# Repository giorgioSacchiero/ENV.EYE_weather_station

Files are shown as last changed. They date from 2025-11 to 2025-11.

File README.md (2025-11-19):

# Env.Eye - 20 Years Arduino Contest Project

## Introduzione
ENV.EYE è il progetto di una stazione meteo autonoma sperimentale. L’idea è nata dall’esigenza di dar vita a qualcosa di originale sfruttando le potenzialità e le versatilità delle soluzioni Arduino. 
Nel nostro caso abbiamo voluto rivisitare il modello classico della stazione meteo IoT, con alcune peculiarità: un contatore Geiger capace di funzionare con un’alimentazione in bassissima tensione (attorno ai 2.2 Volt) e la possibilità di rendere il tutto indipendente attraverso un pannello fotovoltaico e due supercondensatori come riserva di energia. Ciò ci ha ovviamente vincolati a prestare la massima attenzione ai consumi, in ogni operazione e/o misura eseguita.
Complessivamente il progetto si occupa della raccolta delle variabili caratteristiche dell’ambiente (temperatura, umidità, pressione atmosferica, ecc.) e del loro caricamento on-line come un’occhio sull’ambiente, da cui il nome “Env.Eye”. 
Per raggiungere lo scopo sono stati realizzati due dispositivi: un modulo chiamato Spot che raccoglie e invia i dati ambientali al secondo modulo chiamato Hub, che ha il compito di rendere disponibili i dati acquisiti in una bacheca on-line realizzata con Arduino Cloud.

## Elettronica (./hardware/Electronics/)
Il progetto si compone di due PCB ciascuna relativa ad uno dei due moduli.
1. La PCB del modulo SPOT incorpora tutta la sensoristica, la sezione di ricarica e alimentazione, il modulo di comunicazione e la scheda Arduino Nano ESP32.
2. La PCB del modulo HUB, più semplice, si compone di un modulo LoRa per la comunicazione radio, un ulteriore scheda Arduino Nano ESP32 ed una terna di LED RGB a indicarne lo stato.

Per l'assemblaggio delle schede è fortemente consigliato ordinare uno stencil poiché semplifica e velocizza il lavoro. Quest'ultimo è acquistabile assieme alle PCB una volta caricato il file di produzione nell'interfaccia del produttore scelto. Nel nostro caso, ci siamo affidati a [JLC-PCB](https://jlcpcb.com/).

I file di progetto sono realizzati su EasyEDA e sono disponibili nella cartella indicata nel titoletto.

**NOTA:** La rev1 presenta dei malfunzionamenti. A breve verrà resa disponibile la versione corretta.

## Meccanica e File CAD (./hardware/CAD/)

## Programmazione (./software/)
Il firmware di Spot e Hub sono disponibili nella cartella sopra indicata. Per la programmazione del primo è stato usato Visual Studio Code con l'estensione ESP-IDF di Espressif. Invece, per quanto riguarda il secondo, è programmato nell'interfaccia Arduino Cloud, oppure attraverso Arduino IDE 2.0.

## Licenza
L'intero progetto è disponibile per il riutilizzo e la modifica sotto licenza CC BY-NC 4.0. Qualsiasi utilizzo commerciale è vietato salvo esplicita autorizzazione dei sottoscritti autori:
1. Giacomo Pascon - (www.progettipascon.altervista.org) - giacomo.pascon@gmail.com 
2. Cristian Piccone - cristian.piccone@gmail.com
3. Giorgio Sacchiero - sacchiero2005@gmail.com

Ulteriori informazioni sono presenti nel file LICENSE.txt e a [questo link](https://creativecommons.org/licenses/by-nc/4.0/).

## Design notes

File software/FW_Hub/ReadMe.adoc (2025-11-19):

:Author: ar-giacomo
:Email:
:Date: 26/09/2025
:Revision: version#
:License: Public Domain

= Project: {Project}

Describe your project

== Step 1: Installation
Please describe the steps to install this project.

For example:

1. Open this file
2. Edit as you like
3. Release to the World!

== Step 2: Assemble the circuit

Assemble the circuit following the diagram layout.png attached to the sketch

== Step 3: Load the code

Upload the code contained in this sketch on to your board

=== Folder structure

....
 sketch123                => Arduino sketch folder
  ├── sketch123.ino       => main Arduino file
  ├── schematics.png      => (optional) an image of the required schematics
  ├── layout.png          => (optional) an image of the layout
  └── ReadMe.adoc         => this file
....

=== License
This project is released under a {License} License.

=== Contributing
To contribute to this project please contact: 

=== BOM
Add the bill of the materials you need for this project.

|===
| ID | Part name      | Part number | Quantity
| R1 | 10k Resistor   | 1234-abcd   | 10       
| L1 | Red LED        | 2345-asdf   | 5        
| A1 | Arduino Zero   | ABX00066    | 1        
|===

=== Help
This document is written in the _AsciiDoc_ format, a markup language to describe documents. 
If you need help you can search the http://www.methods.co.nz/asciidoc[AsciiDoc homepage]
or consult the http://powerman.name/doc/asciidoc[AsciiDoc cheatsheet]

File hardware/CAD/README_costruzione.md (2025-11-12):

parte meccanica / costruttiva:
- materiali:
    - filo o-ring / diam: 1.6 mm / lenght: 1 m;
    - 4 inserti M3 in ottone da inrerire a caldo;
    - 4 viti M3 con testa svasata;
    - 3 piedini M3 per PCB spessi 5mm;
    - maschi M3, M4 per filettare;
    - tavola di legno spessa 10/15 mm;
    - profili a "L" in acciaio.

- componenti:
    I componenti della scatola si trovano nella cartella "componenti" divisi tra le cartelle "Spot" e "Hub". I componenti da utilizzare nella costruzione sono le ultime versioni dei componenti, identificate dal pedice "_v3" per la verione 3 di un file. 

- stampe 3D:
    Consiglio per lo Spot è quello di stampare in materiali resistenti come PETG o ABS (io ho utilizzato PETG), mentre per l'Hub consiglio un materiale traslucido anche se poco resistente. questo perché il modulo presenta 3 led di diagnostica che devono essere visibili         dall'esterno.

- montaggio:
  - Spot:
    - Inserire a caldo gli inserti in ottone nei 4 fori sotto il componente "scatola_corpo_v3" e fissare il "tappino_TPU" sulla posta della USB con una vitina molto piccola, attorno a una M2 (va bene una vite autofilettante come no, a scelta);
    - tagliare a misura l'o-ring, inserirlo nella corsia tra "scatola_corpo_v3" e "scatola_coperchio_principale" e incollarne le estremità l'una con l'altra con dell'attach;
    - filettare i 3 fori delle torrette del coperchio_principale con maschio M3 e avvitarci i 3 piedini in ottone;
    - tagliare la tavola di legno con le misure del componente "legno" (trascurare lo spessore) e realizzare indicativamente il resto della struttura con cui ancorare lo spot a un qualsiasi supporto verticale;
    - praticare un foro sulla superficie inclinata della scatola per permettere il passaggio dei fili del pannello e incollarci sopra il pannello solare con del silicone per impermeabilizzare;
    - montare la scatola sulla tavola con viti autofilettanti per legno, mantenendo una spaziatura al di sotto della scatola di almeno 5 mm (lo spessore di un dado M4 / M5);
    - praticare sulla parte restante della tavola 8 fori filettati M4 per montare anemometro e pala per la direzione del vento e montarli.
      
        [fare attenzione a filettare i fori dal punto in cui la vite verrà avvitata, perchè potrebbe non essere abbastanza lungo il maschio per filettare fin dall'altra parte della tavola. Inoltre curarci di praticare bene i fori per non risciare disallineamenti]; 
    - connettere i sensori esterni alla scheda e chiudere il tutto.
     
  - Hub:

      molto più semplice dello Spot, basta inserire la schedina dell'Hub nella cava disegnata allo scopo, volendo fissare la scheda con viti M3 nei due fori della scheda e incastrare parte sotto con parte sopra. Fine.

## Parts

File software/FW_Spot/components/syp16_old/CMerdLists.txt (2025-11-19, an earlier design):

idf_component_register(SRCS "syp16.cpp" INCLUDE_DIRS "." REQUIRES driver)

target_compile_options(${COMPONENT_LIB} PRIVATE -std=gnu++23)

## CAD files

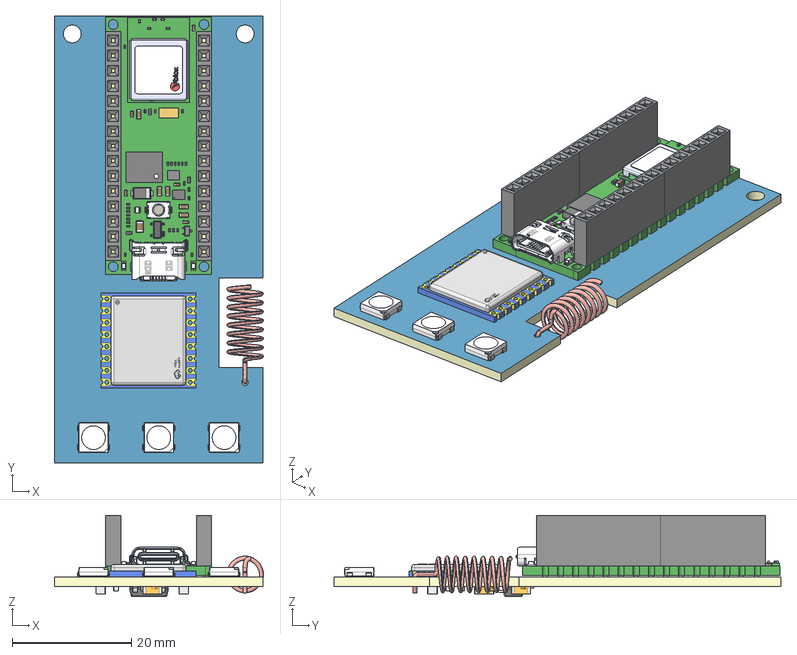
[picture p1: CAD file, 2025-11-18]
hardware/CAD/PCB_Models/PCB_hub_rev_0/PCB_hub_rev_0.step
35.1 x 75.0 x 13.6 mm
Board~ZvB2
TopCopper~ZvB2
BottomCopper~ZvB2
TopFpcStiffener~ZvB2
BottomFpcStiffener~ZvB2
Arduino_NANO_ESP32~libraries\Arduino_NANO_ESP32.step~ZvB2 x 184
C1206~C1206_L3.2-W1.6-H1.3~ZvB2 x 3
C0603~C0603_L1.6-W0.8-H0.8~ZvB2 x 3
LED-SMD_4P-L5.0-W5.0-BL_XL-5050RGBC~LED-SMD_4P-L5.0-W5.0-BL_ XL-5050RGBC~ZvB2 x 3
SOT-223-3_L6.5-W3.4-P2.30-LS7.0-BR-1~SOT-223-3_ L6.5-W3.4-P2.30-LS7.0-BR-1~ZvB2
COMM-SMD_LORA1276-C1-915MHZ~COMM-SMD_LORA1276-C1-915MHZ~ZvB2
ANT-TH_VG868SNX18-5W2~ANT-TH_VG868SNX18-5W2~ZvB2

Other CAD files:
hardware/CAD/OldVersions/Assembly1.0022.iam
hardware/CAD/OldVersions/adattatore per motore.0001.ipt
hardware/CAD/OldVersions/asta.0006.ipt
hardware/CAD/OldVersions/cupola alta di protezione.0007.ipt
hardware/CAD/OldVersions/guarnizione motore.0004.ipt
hardware/CAD/OldVersions/lampione.0001.ipt
hardware/CAD/OldVersions/legno 1.0001.ipt
hardware/CAD/OldVersions/legno 2.0004.ipt
hardware/CAD/OldVersions/legno.0007.ipt
hardware/CAD/OldVersions/pannello solare.0003.ipt
hardware/CAD/OldVersions/piedino.0001.ipt
hardware/CAD/OldVersions/sacatola coperchio principale.0019.ipt
hardware/CAD/OldVersions/scatola - corpo sotto.0004.ipt
hardware/CAD/OldVersions/scatola corpo.0024.ipt
hardware/CAD/OldVersions/spazzola - asta.0002.ipt
hardware/CAD/OldVersions/spazzola - spazzola.0002.ipt
hardware/CAD/OldVersions/supporto asta.0003.ipt
hardware/CAD/OldVersions/tappino tpu.0001.ipt
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

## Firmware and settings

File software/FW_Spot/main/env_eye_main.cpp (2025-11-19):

/* ------------------------- C++ (.cpp) FILE INFORMATION ------------------------- */
/**
 * PROJECT:         ENV.EYE SPOT Project
 * 
 * FILE:            "env_eye_main.cpp"
 * 
 */

#include <stdio.h>
#include <stdlib.h>
#include <inttypes.h>
#include <math.h>
#include "freertos/FreeRTOS.h"
#include "freertos/task.h"

#include "esp_log.h"
#include "driver/gpio.h"
#include "driver/rtc_io.h"
#include "driver/ledc.h"
#include "esp_adc/adc_oneshot.h"
#include "esp_sleep.h"
#include "esp_timer.h"

#include "nano_esp32.hpp"
#include "hdc1080.hpp"
#include "wf183de.hpp"
#include "syp16.hpp"
#include "lora.h"

#include "env_eye_pinout.h"
#include "env_eye_config.h"
#include "env_eye_lora.hpp"

/* ------------------------- MACRO DEFINITION -------------------------*/
#define TAG "SPOT"

#define ERR_LOG_RET_ERR(FUNCT)  \
if ( esp_err_t _ERR = FUNCT != ESP_OK ) \
{   \
    ESP_LOGE(TAG, "ERROR (%X) at line %d. Description: %s", _ERR, __LINE__, esp_err_to_name(_ERR)); \
    return _ERR; \
}

/* ------------------------- NAMESPACES ------------------------- */
using namespace Nano_ESP32;

/* ------------------------- GLOBAL VARIABLES ------------------------- */
adc_oneshot_unit_handle_t adc_unit_handle;
RTC_DATA_ATTR int wakeup_count = 0;
enum direction_t {N, NE, E, SE, S, SW, W, NW, UNK};
uint16_t geiger_pulses = 0;

/* ------------------------- LOCAL FUNCTIONS ------------------------- */
esp_err_t gpio_configure();

inline void sensor_5v_turn_on();
inline void sensor_5v_turn_off();

inline void sensor_3v3_turn_on();
inline void sensor_3v3_turn_off();

inline void sensor_25v_turn_on();
inline void sensor_25v_turn_off();

inline void geiger_25v_turn_on();
inline void geiger_25v_turn_off();

inline void geiger_5v_turn_on();
inline void geiger_5v_turn_off();

inline void geiger_turn_on();
inline void geiger_turn_off();

float get_wind_speed();
direction_t get_wind_dir();

float get_noise_level();

float get_pollution_level(SYP16 _syp);

void geiger_isr(void *_args);
float get_radiation_level();

void lora_send_packet(lora_payload_t *_payload);

void esp_enter_sleep();

extern "C" void app_main(void)
{
    //Wait some time for serial monitor connection
    vTaskDelay(100);

    //Configure GPIO
    ESP_ERROR_CHECK(configure_nano());
    ESP_ERROR_CHECK(gpio_configure());

    //Turn on 3.3V sensor rail and initialize communicatin
    sensor_3v3_turn_on();
    vTaskDelay(100);
    
    HDC1080 hdc(rev1_pinout.I2C_SDA, rev1_pinout.I2C_SCL, 100000, I2C_NUM_0, 1000, true);
    hdc.configureDefault();
    WF183DE wf(rev1_pinout.I2C_SDA, rev1_pinout.I2C_SCL, 100000, I2C_NUM_0, 1000, false);
    
    //Configure LoRa module
    lora_configure(100000, 868000000, 7, 7, 1, true);

    vTaskDelay(100);
    ESP_LOGE(TAG, "Wakeup num %d", wakeup_count);

    while(1)
    {
        lora_payload_t payload;
        lora_init_payload(&payload);

        switch(wakeup_count)
        {
            //----> FIRST START, wait some time before measuring.
            case 0:
                wakeup_count++;
                esp_enter_sleep();
                break;
            
            //----> MEASURE ONLY TEMP., HUM. AND PRESSURE
            case 1:     
                hdc.measure();

                //Perform two measures to avoid null reading
                wf.measurePressure();
                vTaskDelay(10);
                wf.measurePressure();

                payload.temperature = hdc.getTemp();
                payload.humidity = hdc.getHum();
                payload.air_pressure = wf.getPressure();
                
                lora_send_packet(&payload);
                //wait for Lora module to send the data before shutting off
                vTaskDelay(100);
                sensor_3v3_turn_off();
                
                wakeup_count++;
                esp_enter_sleep();
            break;
            
            //----> MEASURE TEMP., HUM., PRESSURE AND WIND
            case 2:
                hdc.measure();
                
                //Perform two measures to avoid null reading
                wf.measurePressure();
                vTaskDelay(10);
                wf.measurePressure();

                payload.temperature = hdc.getTemp();
                payload.humidity = hdc.getHum();
                payload.air_pressure = wf.getPressure();
                
                if(gpio_get_level(rev1_pinout.CAP_VOLTAGE_OK))
                {
                    sensor_25v_turn_on();
                    vTaskDelay(150);
                    payload.wind_spd = get_wind_speed();
                    payload.wind_dir = (int16_t)get_wind_dir();
                    sensor_25v_turn_off();
                
                    sensor_5v_turn_on();
                    vTaskDelay(300);
                    payload.noise_level = get_noise_level();
                    sensor_5v_turn_off();

                    wakeup_count++;
                }
                else wakeup_count = 1;
                
                lora_send_packet(&payload);
                vTaskDelay(100);
                //wait for Lora module to send the data before shutting off
                sensor_3v3_turn_off();                

                esp_enter_sleep();
            break;

            //----> MEASURE TEMP., HUM., PRESSURE, BACKGR. NOISE AND RADIATION 
            case 3: //temp + hum + press + mic + geig
                hdc.measure();
                
                //Perform two measures to avoid null reading
                wf.measurePressure();
                vTaskDelay(10);
                wf.measurePressure();

                payload.temperature = hdc.getTemp();
                payload.humidity = hdc.getHum();
                payload.air_pressure = wf.getPressure();
 
                if(gpio_get_level(rev1_pinout.CAP_VOLTAGE_OK))
                {               
                    sensor_5v_turn_on();
                    vTaskDelay(300);
                    payload.noise_level = get_noise_level();
                    sensor_5v_turn_off();

                    geiger_turn_on();
                    vTaskDelay(50);
                    float usievert_h = get_radiation_level();
                    if(usievert_h != -1) 
                    {
                        payload.radiation_level = usievert_h;
                        wakeup_count++;
                    }
                    geiger_turn_off();
                }
                
                lora_send_packet(&payload);
                vTaskDelay(100);
                //wait for Lora module to send the data before shutting off
                sensor_3v3_turn_off();                
                esp_enter_sleep();
            break;

            //----> MEASURE TEMP., HUM., PRESSURE, BACKGR. NOISE AND POLLUTION 
            case 4: //temp + hum + press + wind + mic + air
                hdc.measure();
                
                //Perform two measures to avoid null reading
                wf.measurePressure();
                vTaskDelay(10);
                wf.measurePressure();

                payload.temperature = hdc.getTemp();
                payload.humidity = hdc.getHum();
                payload.air_pressure = wf.getPressure();

                if(gpio_get_level(rev1_pinout.CAP_VOLTAGE_OK))
                {
                    sensor_5v_turn_on();
                    vTaskDelay(150);
                    SYP16 syp(rev1_pinout.UART_TX, rev1_pinout.UART_RX, UART_NUM_1, SYP16_QUESTION_ANSWER_MODE);
                    vTaskDelay(150);
                    payload.noise_level = get_noise_level();
                
                    payload.air_pollution_level = get_pollution_level(syp);
                    wakeup_count = 2; //Start again from measuring wind 
                }
                //When supercapacitors have low charge, measure with geiger first, since it draws less power.
                else wakeup_count = 3;
                sensor_5v_turn_off();

                lora_send_packet(&payload);
                vTaskDelay(100);
                sensor_3v3_turn_off();
                
                esp_enter_sleep();
            break;
        }

        vTaskDelay(100); //Never reached in normal operation
    }
}

/* ------------------------- GPIO Management ------------------------- */
esp_err_t gpio_configure()
{
    //Initialize digital inputs
    gpio_config_t _pin_config;
    _pin_config.mode = GPIO_MODE_INPUT;
    _pin_config.intr_type = GPIO_INTR_DISABLE;
    _pin_config.pin_bit_mask = 1ULL << rev1_pinout.CAP_VOLTAGE_OK | 1ULL<<rev1_pinout.GEIGER_IN;
    _pin_config.pull_down_en = GPIO_PULLDOWN_DISABLE;
    _pin_config.pull_up_en = GPIO_PULLUP_ENABLE;
    ERR_LOG_RET_ERR(gpio_config(&_pin_config));

    //Geiger input interrupt
    gpio_set_intr_type(rev1_pinout.GEIGER_IN, GPIO_INTR_NEGEDGE);
    gpio_install_isr_service(ESP_INTR_FLAG_IRAM);
    gpio_isr_handler_add(rev1_pinout.GEIGER_IN, geiger_isr, NULL);
    gpio_intr_disable(rev1_pinout.GEIGER_IN);

    //Initialize digital outputs
    _pin_config.mode = GPIO_MODE_OUTPUT;
    _pin_config.pin_bit_mask = 1ULL<<rev1_pinout.EN_3V3_RAIL;
    ERR_LOG_RET_ERR(gpio_config(&_pin_config));
    ERR_LOG_RET_ERR(gpio_set_level(rev1_pinout.EN_3V3_RAIL, 1));

    _pin_config.pin_bit_mask = 1ULL<<rev1_pinout.EN_5V_SENSOR_RAIL | 1ULL<<rev1_pinout.EN_5V_GEIGER_RAIL | 1ULL<<rev1_pinout.EN_25V_RAIL | 1ULL<<rev1_pinout.EN_SERVO_RAIL;
    _pin_config.pull_down_en = GPIO_PULLDOWN_DISABLE;
    _pin_config.pull_up_en = GPIO_PULLUP_DISABLE;
    ERR_LOG_RET_ERR(gpio_config(&_pin_config));
    ERR_LOG_RET_ERR(gpio_set_level(rev1_pinout.EN_5V_SENSOR_RAIL, 0));
    ERR_LOG_RET_ERR(gpio_set_level(rev1_pinout.EN_5V_GEIGER_RAIL, 0));
    ERR_LOG_RET_ERR(gpio_set_level(rev1_pinout.EN_25V_RAIL, 0));
    ERR_LOG_RET_ERR(gpio_set_level(rev1_pinout.EN_SERVO_RAIL, 0));
    
    //Initialize analog inputs
    adc_oneshot_unit_init_cfg_t _unit_config;
    _unit_config.unit_id = ADC_UNIT_1;
    _unit_config.ulp_mode = ADC_ULP_MODE_DISABLE;
    ERR_LOG_RET_ERR(adc_oneshot_new_unit(&_unit_config, &adc_unit_handle));

    adc_oneshot_chan_cfg_t _channel_config;
    _channel_config.bitwidth = ADC_BITWIDTH_DEFAULT;
    _channel_config.atten = ADC_ATTEN_DB_12;
    ERR_LOG_RET_ERR(adc_oneshot_config_channel(adc_unit_handle, rev1_pinout.MIC_IN, &_channel_config));
    ERR_LOG_RET_ERR(adc_oneshot_config_channel(adc_unit_handle, rev1_pinout.WIND_SPEED_IN, &_channel_config));
    ERR_LOG_RET_ERR(adc_oneshot_config_channel(adc_unit_handle, rev1_pinout.WIND_DIR_IN, &_channel_config));

    return ESP_OK;
}

// -------- Toggle 3V3 rail -------- 
inline void sensor_3v3_turn_on()
{
    gpio_set_level(rev1_pinout.EN_3V3_RAIL, 0);
}

inline void sensor_3v3_turn_off()
{
    gpio_set_level(rev1_pinout.EN_3V3_RAIL, 1);
}

// -------- Toggle 5V sensor rail -------- 
inline void sensor_5v_turn_on()
{
    gpio_set_level(rev1_pinout.EN_5V_SENSOR_RAIL, 1);
}

inline void sensor_5v_turn_off()
{
    gpio_set_level(rev1_pinout.EN_5V_SENSOR_RAIL, 0);
}

// -------- Toggle 5V geiger rail --------
inline void geiger_5v_turn_on()
{
    gpio_set_level(rev1_pinout.EN_5V_GEIGER_RAIL, 1);
}

inline void geiger_5v_turn_off()
{
    gpio_set_level(rev1_pinout.EN_5V_GEIGER_RAIL, 0);
}

// -------- Toggle 25V rail -------- 
inline void sensor_25v_turn_on()
{
    gpio_set_level(rev1_pinout.EN_SERVO_RAIL, 1);
}

inline void sensor_25v_turn_off()
{
    gpio_set_level(rev1_pinout.EN_SERVO_RAIL, 0);
}

// -------- Toggle 25V rail for geiger supply -------- 
inline void geiger_25v_turn_on()
{
    gpio_set_level(rev1_pinout.EN_25V_RAIL, 1);
}

inline void geiger_25v_turn_off()
{
    gpio_set_level(rev1_pinout.EN_25V_RAIL, 0);
}

// -------- Toggle geiger supply --------
inline void geiger_turn_on()
{
    geiger_25v_turn_on();
    geiger_5v_turn_on();
}

inline void geiger_turn_off()
{
    geiger_25v_turn_on();
    geiger_5v_turn_off();
}

//--------Wind Measurements--------
float get_wind_speed()
{
    int _raw_wind;
    if(adc_oneshot_read(adc_unit_handle, rev1_pinout.WIND_SPEED_IN, &_raw_wind) != ESP_OK)
    {
        return -99; //sost con latest_wind_spd
    }
    return (60*_raw_wind/4095.0);
}

direction_t get_wind_dir()
{
    int _raw_direction;
    direction_t _dir;
    if(adc_oneshot_read(adc_unit_handle, rev1_pinout.WIND_DIR_IN, &_raw_direction) != ESP_OK)
        return UNK;

    for(int i = 0; i < 8; i++)
    {   
        if(abs((_raw_direction - WIND_DIR_CALIBRATION[i])) > WIND_DIR_STEP_DELTA)
            continue;
        else _dir = (direction_t)i;
        vTaskDelay(1);
    }
    //adjust for mounting direction
    return (direction_t)(((int)_dir + (int)MOUNT_DIRECTION) % 8);  
}

//--------Noise Measurement--------
float get_noise_level()
{
    int _raw_noise;
    uint64_t mean_noise = 0;
    for(int i=0;i<MIC_SAMPLE_NUM;i++)
    {
        ESP_ERROR_CHECK_WITHOUT_ABORT(adc_oneshot_read(adc_unit_handle, rev1_pinout.MIC_IN, &_raw_noise));
        mean_noise += abs(_raw_noise - MIC_DC_OFFSET);
        vTaskDelay(1);
    }
    return 10*log(mean_noise*2/MIC_SAMPLE_NUM) + MIC_DB_OFFSET;
}

//--------Pollution Measurement--------
float get_pollution_level(SYP16 _syp)
{
    uint64_t _start_time = esp_timer_get_time();
    while((esp_timer_get_time() - _start_time) < 180000000L)
    {
        vTaskDelay(1);
        if(!gpio_get_level(rev1_pinout.CAP_VOLTAGE_OK))
            return -99;
    }
    ESP_ERROR_CHECK(_syp.measure());
    while(!_syp.dataAvailable()) vTaskDelay(1);
    return _syp.getGasConcentration();
}

//--------Radiation Measurement--------
void geiger_isr(void *_args)
{
    if(geiger_pulses < 0xFFFF) geiger_pulses++;
}

float get_radiation_level()
{
    //Enable counting
    gpio_intr_enable(rev1_pinout.GEIGER_IN);

    //Wait 15s to get the measurements
    uint64_t _start_time = esp_timer_get_time();
    while(((esp_timer_get_time() - _start_time) <= 15000000) && gpio_get_level(rev1_pinout.CAP_VOLTAGE_OK))
    {   
        vTaskDelay(1);
        if(!gpio_get_level(rev1_pinout.CAP_VOLTAGE_OK))
        {
            gpio_intr_disable(rev1_pinout.GEIGER_IN);
            return -1;
        } 
    }
    gpio_intr_disable(rev1_pinout.GEIGER_IN);
    return (float)geiger_pulses * GEIGER_USV_HOUR_PER_PULSE_S / 15.0;
}

//--------LoRa send packet--------
void lora_send_packet(lora_payload_t *_payload) //finire payload
{   
    lora_packet_t _to_send;
    _to_send.data.module_id = SPOT_MODULE_ID;
    _to_send.data.wakeup_num = wakeup_count;
    _to_send.data.temperature = ( (_payload->temperature != -99) ? round<int16_t>(_payload->temperature*100) : -99 );
    _to_send.data.humidity = ( (_payload->humidity != -99) ? round<int16_t>(_payload->humidity*100) : -99 );
    _to_send.data.air_pressure = ( (_payload->air_pressure != -99) ? round<int32_t>(_payload->air_pressure) : -99 );
    _to_send.data.air_pollution_level = ( (_payload->air_pollution_level != -99) ? round<int16_t>(_payload->air_pollution_level*100) : -99 );
    _to_send.data.wind_spd = ( (_payload->wind_spd != -99) ? round<int16_t>(_payload->wind_spd*100) : -99 );
    _to_send.data.wind_dir = ( (_payload->wind_dir != -99) ? (int16_t)_payload->wind_dir*100 : -99 );
    _to_send.data.noise_level = ( (_payload->noise_level != -99) ? round<int16_t>(_payload->noise_level*100) : -99 );
    _to_send.data.radiation_level = ( (_payload->radiation_level != -99) ? round<int16_t>(_payload->radiation_level*100) : -99 );
    ESP_ERROR_CHECK_WITHOUT_ABORT(lora_send_measurement_data(&_to_send)); //return
}

void esp_enter_sleep()
{
    esp_sleep_enable_timer_wakeup(SLEEP_TIME_US);
    esp_deep_sleep_start();
}

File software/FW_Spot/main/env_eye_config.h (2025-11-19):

#pragma once
/* ------------------------- HEADER (.h) FILE INFORMATION ------------------------- */
/**
 * PROJECT:         ENV.EYE SPOT Project
 * 
 * FILE:            "env_eye_config.h"
 * DESCRIPTION:     Eve.Eye SPOT configuration options.
 * 
 */

#define SPOT_MODULE_ID 0
#define SLEEP_TIME_US 30*1000000//15*60*1000000 //15 Min.

#define MOUNT_DIRECTION N
#define WIND_DIR_STEP_DELTA 50
const int WIND_DIR_CALIBRATION[8] =
{
    0,      //W
    540,    //SW
    1085,   //S
    1650,   //SE
    2220,   //E
    2800,   //NE
    3435,   //N
    4095    //NW
};

#define MIC_DC_OFFSET 2160
#define MIC_SAMPLE_NUM 50
#define MIC_DB_OFFSET 5

#define GEIGER_USV_HOUR_PER_PULSE_S 0.39 

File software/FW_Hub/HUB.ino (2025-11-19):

#include "arduino_secrets.h"
/* ------------------------- C/C++ (.ino) FILE INFORMATION ------------------------- */
/**
 * PROJECT:         ENV.EYE HUB Project
 * 
 * FILE:            "HUB.ino"
 * DESCRIPTION:     Eve.Eye HUB main.
 * 
 */

#include <math.h>

#include "thingProperties.h"
#include "lora_conf.h"
#include "led_mgmt.h"

ArduinoIoTCloudEvent last_event = ArduinoIoTCloudEvent::DISCONNECT;
bool packet_fade_triggered = false;
lora_packet_t _rx_packet;

void callback_sync()
{
  led_fade(0,1,0, 1, true, 5000);
  last_event = ArduinoIoTCloudEvent::SYNC;
}

void callback_connect()
{
  led_fade(0, 0, 1, 1, false, 5000);
  last_event = ArduinoIoTCloudEvent::CONNECT;
}

void callback_disconnect()
{
  led_fade(1, 0, 0, 1, false, 5000);
  last_event = ArduinoIoTCloudEvent::DISCONNECT;
}

float round_to_dp( float in_value, int decimal_place )
{
	float multiplier = powf( 10.0f, decimal_place );
	in_value = roundf( in_value * multiplier ) / multiplier;
	return in_value;
}

void setup() {
  // Initialize serial and wait for port to open:
  Serial.begin(115200);
  // This delay gives the chance to wait for a Serial Monitor without blocking if none is found
  delay(3000);

  //Initialize LoRa Module
  lora_begin();

  // Defined in thingProperties.h
  initProperties();

  //Initialize RGB led management
  led_begin();

  // Connect to Arduino IoT Cloud
  ArduinoCloud.begin(ArduinoIoTPreferredConnection);
  ArduinoCloud.addCallback(ArduinoIoTCloudEvent::CONNECT, callback_connect);
  ArduinoCloud.addCallback(ArduinoIoTCloudEvent::DISCONNECT, callback_disconnect);
  ArduinoCloud.addCallback(ArduinoIoTCloudEvent::SYNC, callback_sync);

  setDebugMessageLevel(2);
  ArduinoCloud.printDebugInfo();

  //Start fading red
  led_fade(1, 0, 0, 1, false, 500);
}

void loop() 
{
  //Update Cloud
  ArduinoCloud.update();

  //Reset fading mode after packet reception
  if(packet_fade_triggered && led_fade_end())
  {
    led_fade_reset();
    packet_fade_triggered = false;
    switch(last_event)
    {
      case ArduinoIoTCloudEvent::CONNECT: callback_connect(); break;
      case ArduinoIoTCloudEvent::SYNC: callback_sync(); break;
      case ArduinoIoTCloudEvent::DISCONNECT: callback_disconnect(); break;
    }
  }

  if(lora_receive(&_rx_packet))
  {    
    //Fade white
    led_fade_reset();
    led_fade(1, 1, 1, 2, true, 5000);
    packet_fade_triggered = true;

    if(_rx_packet.data.temperature != -99)
      temperature = round_to_dp(((float)_rx_packet.data.temperature/100),2);

    if(_rx_packet.data.humidity != -99 && _rx_packet.data.humidity >= 0)
      humidity = (float)_rx_packet.data.humidity/100;

    if(_rx_packet.data.air_pressure != -99 && _rx_packet.data.air_pressure >= 0)
      pressure = _rx_packet.data.air_pressure;
    
    if(_rx_packet.data.air_pollution_level != -99 && _rx_packet.data.air_pollution_level >= 0)
      pollution = round_to_dp(((float)_rx_packet.data.air_pollution_level/100),2);

    if(_rx_packet.data.noise_level != -99)
      noiselevel = round_to_dp(((float)_rx_packet.data.noise_level/100),2);

    if(_rx_packet.data.radiation_level != -99 && _rx_packet.data.radiation_level >= 0)
      radiationlevel = round_to_dp(((float)_rx_packet.data.radiation_level/100),2);

    if(_rx_packet.data.wind_spd != -99 && _rx_packet.data.wind_spd >= 0)
      windspeed = round_to_dp(((float)_rx_packet.data.wind_spd/100),2);

    if(_rx_packet.data.wind_dir != -99)
    {
      switch(_rx_packet.data.wind_dir)
      {
        case 0: winddir = "N"; break;
        case 1: winddir = "NE"; break;
        case 2: winddir = "E"; break;
        case 3: winddir = "SE"; break;
        case 4: winddir = "S"; break;
        case 5: winddir = "SO"; break;
        case 6: winddir = "O"; break;
        case 7: winddir = "NO"; break;
        default: winddir = "UNK"; break;
      }
    }
  }
}

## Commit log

2025-11-05 Inserimento file CAD
    [3D_PCB1_2025-08-10.iam, 3D_Sensor_Module_Rev_0_2025-09-11.0001.iam, 3D_Sensor_Module_Rev_0_2025-09-11.iam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]
2025-11-18 Sistemazione File
    [3D_PCB1_2025-08-10.iam, 3D_Sensor_Module_Rev_0_2025-09-11.0001.iam, 3D_Sensor_Module_Rev_0_2025-09-11.iam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]
